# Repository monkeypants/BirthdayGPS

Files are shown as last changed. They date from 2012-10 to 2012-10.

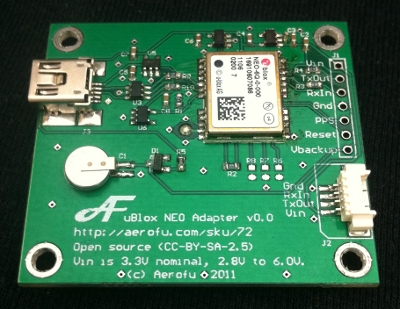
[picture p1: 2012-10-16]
images/bottom_cropped_400.jpg

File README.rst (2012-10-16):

BirthdayGPS v0.1
================

These files are hardware designs for the BirthdayGPS, more information is available here:

http://aerofu.com/index.php?products_id=72

or here:

http://aerofu.com/sku/72

The designs are free open source, released under the CC-BY-SA licence, available here:

http://creativecommons.org/licenses/by-sa/2.5/

Copyright is held by Chris Gough (a.k.a. aerofu.com).

Attribution
-----------

Attribution in derived works must includes both a link to the aerofu.com web site and an appropriate reference the BirthdayGPS brand name.

Share Alike
-----------

Derived works must be made available under CC-BY-SA licence version 2.5 or later. It is not permitted to distribute a derived work a more restrictive licence, such as with a "non-commercial" clause for example.

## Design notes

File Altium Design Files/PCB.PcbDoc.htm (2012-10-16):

Altium Reporting Options

# File in Previous Format

Date | : | 7/31/2012
Time | : | 1:21:46 PM
Filename | : | D:\from_old_workstation\personal\BirthdayGPS\Birthday GPS v0.1\Altium Design Files\PCB.PcbDoc

Version | Warning
Summer 09 | CAUTION - File contains old violation objects. These violations are no longer supported & will not be loaded.Please run DRC after opening this file in order to refresh the violations.
Summer 09 | CAUTION - Existing testpoint rules and settings are used as fabrication testpoint information.

This file was generated by an earlier version of the software

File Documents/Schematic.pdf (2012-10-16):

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
D | D
C | C
B | B
A | A

1

AeroFu
PO Box 5166
Kingston
NSW
1 | Australia 2606

## uBlox NEO Adapter

0.1
03/02/2012
Andrew Gough, copyright Aerofu 2011, Open source (CC-BY-SA-2.5). See http://aerofu.com/sku/72 for details.

Title

Size: | Number:
Date:
Author:

Revision:
Sheet of

A4

NC 1
SS_N 2
PPS 3
ExtInt 4
USB_DM 5
USB_DP 6
VddUSB 7

ResetN 8
VccRF 9
Gnd 10
RF_In 11
Gnd 12 | Gnd | 13 MOSI-CFG0 | 14 MISO-CFGCom1 | 15 SCK-CFGGPS0 | 16 NC | 17
SDA2 | 18 SCL2 | 19 TxD | 20 RxD | 21 V_Bckp | 22 Vcc | 23 Gnd | 24

U1

uBlox-Neo

V3.0

1Ant1

Patch Antenna

Pins for hand soldering

V | | | 1
ID | 4 DP | 3 DM | 2
Gnd | | | 5

J3

Molex picoblade

3.0V LDO Regulator | 3.3 LDO Regulator

Vin 1

Vss

2

CE 3 | (NC) | 4
| Vout | 5

U2 LT1761ES5-3

Vin 1

Vss

2

CE 3 | (NC) | 4
| Vout | 5

U5 LT1761ES5-3
Vin 1

Vss

2

CE 3 | (NC) | 4
| Vout | 5

U6 TC1015-3.3VCT713

47K

R1

V3.0

1uF

C5
1uF

C7
1uF

C8

R10 22R

R9 22R

V5-USB

3.0V LDO Regulator

V5-USB | V5-USB

V3.0

1uF

C4

### USB Components - Optional

1
2
3
4

J2

TxOut
RxIn
Gnd

220mF

C1

D1

100R

R5

V3.0

1uF

C2

Vbackup | SCL 1

Vss

2

SDA 3

Vcc | 4
WP | 5

U4

32k EEPROM

V3.0

SCL
SDA

100nF

C6

### Non-Volatile feature components - Optional

Vbackup

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
TxOut
RxIn
Gnd
PPS
Reset
Vbackup

or header

### Interconnect

RxIn
TxOut

Vin
<
<

Reset

PPS

Vin

IO1 1

IO2 3 | GND 2 | IO2 | 4 Vbus | 5 IO1 | 6

U3

ESD Protection | 1uF C3

Vin

### Main Power supply

V5-USB

(Optional)

ESD Protection

3.3K

R2

DNF

R7
DNF

R6
DNF

R8

CFG-GPS

CFG-C0

CFG-C1

R5 Allows the use of external reset.

DM
DP
M1 | M2 | M3 | M4

R3 1K
R4 1K

R3 and R4 protect IO from different logic levels.

R6, R7, R8 can be used

Mount holes

For normal use, Only Vin, Rx, Tx and Gnd need be connected.

V3.3-USB

for configuration.

# Notes:

Vin should be between 2.8V and 6V. Lower voltages mean that the uBlox Neo might not receive it's required minimum voltage of 2.7V. Higher voltages will generate more heat in the regulator U2, and may reduce operating temperature range.

IO voltages are nominally 3.0V. If connected to 3.3V or 5V logic, R3 will prevent the Rx line from taking too much current through it's rail clamp diode. If connected to 1.8Vlogic, R4 should protect
that devices Rx line likewise. No such protection has been provided for PPS.

The Reset line should only be controlled by an open drain device to avoid contention. A reset generator is provided on board the NEO series, so use of external Reset is optional.

The USB circuit is optional, and allows connection to the NEO through it's USB interface. If USB is not required, then all components in the above box can be removed. R1 is still required.

The power from USB and Vin are both regulated to 3.0V. If both sources are present, there should be no contention as long as regulators with reverse voltage protection are used. The LT1761 regulators have this protection. If only USB operation is required, the main power supply components can be removed.

Micochip 24AA32A

Two forms of non-volatile storage are supported. The Super-cap C1 allows the NEO module to shutdown and preserve it's configuration settings, assistance information and time. It should provide the back-up supply voltage for several hours. Beyond this time, assistance and time data become less usefull for receiver start-up. If the EEPROM is not used, then it is essential to provide the receiver configuration commands on boot every time.

Too preserve the configuration settings, the EEPROM U4 may be used. This is not large enough to allow the receiver to store assistance data. This I2C EEPROM can be removed if not required.

The settings can also be configured by using R6, R7 and R8. These allow CFG-GPS, CFG-Com1 and CFG-Com0 bits to be set on start-up. These can be used to set some of the operating configuration of the NEO unit.

Vbackup can be used to provide an external backup battery. It's voltage must not exceed 3.3V if Super-cap C1 is fitted, or 3.6 V if it is not. If a lower than 3.0V supply is used, either R5 or D1 must be removed.

### LED Indicators - Optional

D2
Green

D3
Red

V3.0 PPS

Two LED's can be used. These are not required. If fitted, D2 will show the presence of power from either Vin or USB. D3 is connected to PPS, and will show the unit is tracking, as long as the PPS is configured for a fairly long pulse, say 100ms. If the PPS is configured for a pulse of several us, then this will not be visible on the LED.

220R

R11
220R

R12

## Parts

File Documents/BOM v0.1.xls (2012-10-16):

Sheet: BOM Report
Bill of Materials
Project: |  | Birthday GPS
Design Version: |  | 0.1
BOM Version: |  | 0.1
Creation Date: | 2012-02-02
Designator | Part | Description | Comment | Source | Alternate Source | Quantity
Ant1 | Taoglas GP.1575.25.4.A.02 | 25 mm Patch antenna | Through Hole, Bottom side | Digikey: 931-1015-ND |  | 1
C1 | Elna DCK-3R3E224U-E | SuperCap, 6.8 mm, 220 mF, 3.3V | SMD, Top side | Digikey: 604-1007-ND |  | 1
C2, C3, C4, C5, C7, C8 | Murata GRM188R61E105KA12D | Capacitor 0603, 1uF, 25V | SMD, Top side | Digikey: 490-3897-1-ND |  | 6
C6 | Murata GRM188R71C104KA01D | Capacitor 0603, 100nF, 16V | SMD, Top side | Digikey: 490-1532-1-ND |  | 1
D1 | Generic Diode BAS116 | Silicon Low Leakage Diode, sot23-3 | SMD, Top side | Digikey: BAS116-FDICT-ND |  | 1
D2 | Osram LG Q971-KN-1 | Green LED, 0603. | SMD, Top side | Digikey: 475-1409-1-ND |  | 1
D3 | Osram LS Q976-NR-1 | Red LED, 0603 | SMD, Top side | Digikey: 475-2512-1-ND |  | 1
J1 | DNF | Graphic only for header | DNF |  |  | 0
J2 | Molex 53261-0471 | 4 pin Molex Picoblade Socket | SMD, Top side | Digikey: WM7622CT-ND |  | 1
J3 | TE 1734035-2 | USB Connector – Mini USB B | SMD, Top side | Digikey: A31727CT-ND |  | 1
M1, M2, M3, M4 | DNF | Graphic only - Mount Holes | DNF |  |  | 0
R1 | Yaego RC0603JR-0747KL | 47k Ohm 0603 Resistor | SMD, Top side | Digikey: 311-47KGRCT-ND |  | 1
R2 | Yaego RC0402JR-073K3L | 3.3k Ohm 0603 Resistor | SMD, Top side | Digikey: 311-3.3KJRCT-ND |  | 1
R3, R4 | Yaego RC0603FR-071KL | 1k Ohm 0603 Resistor | SMD, Top side | Digikey: 311-1.00KHRCT-ND |  | 2
R5 | Yaego RC0402JR-07100RL | 100 Ohm 0603 Resistor | SMD, Top side | Digikey: 311-100JRCT-ND |  | 1
R6, R7, R8 | DNF | DNF Resistors | DNF |  |  | 0
R9, R10 | Yaego RC0603JR-0722RL | 22 Ohm 0603 Resistor | SMD, Top side | Digikey: 311-22GRCT-ND |  | 2
R11, R12 | Yaego RC0603JR-07220RL | 220 Ohm 0603 Resistor | SMD, Top side | Digikey: 311-220GRCT-ND |  | 2
U1 | u-blox Neo 6Q | GPS Module | SMD, Top side | Braemac: uBlox NEO-6Q |  | 1
U2, U5 | Linear Tech LT1761ES5-3 | LDO Regulator, Sot-23-5, 3.0V | SMD, Top side | Digikey: LT1761ES5-3#TRMPBFCT-ND | From Stock | 2
U3 | ST USBLC6-2 | ESD Protection, Sot23-6 | SMD, Top side | Digikey: 497-5235-1-ND |  | 1
U4 | Microchip 24AA32A | EEPROM, 32k, Sot23-5 | SMD, Top side | Digikey: 24AA32AT-I/OTCT-ND |  | 1
U6 | TC1015-3.3VCT713 | LDO Regulator, Sot-23-5, 3.3V | SMD, Top side | Digikey: TC1015-3.3VCT713CT-ND |  | 1
 |  |  |  |  |  | 29
Approved |  | Notes

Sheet: Project Information
Project Full Path | C:\Work\NEO GPS Board\PCB_Project.PrjPCB
Project Filename | PCB_Project.PrjPCB
Variant Name | None
Data-Source Filename | PCB_Project.PrjPCB
Data-Source Full Path | C:\Work\NEO GPS Board\PCB_Project.PrjPCB
Title | Bill of Materials For Project [PCB_Project.PrjPCB] (No PCB Document Selected)
Total Quantity | 37
Report Time | 19:00:43
Report Date | 2012-02-04
Report Date & Tine | 2012-02-04 19:00
Output Name | Bill of Materials
Output Type | BOM_PartType
Output Generator Name | ReportComponents
Output Generator Description | Component Reports

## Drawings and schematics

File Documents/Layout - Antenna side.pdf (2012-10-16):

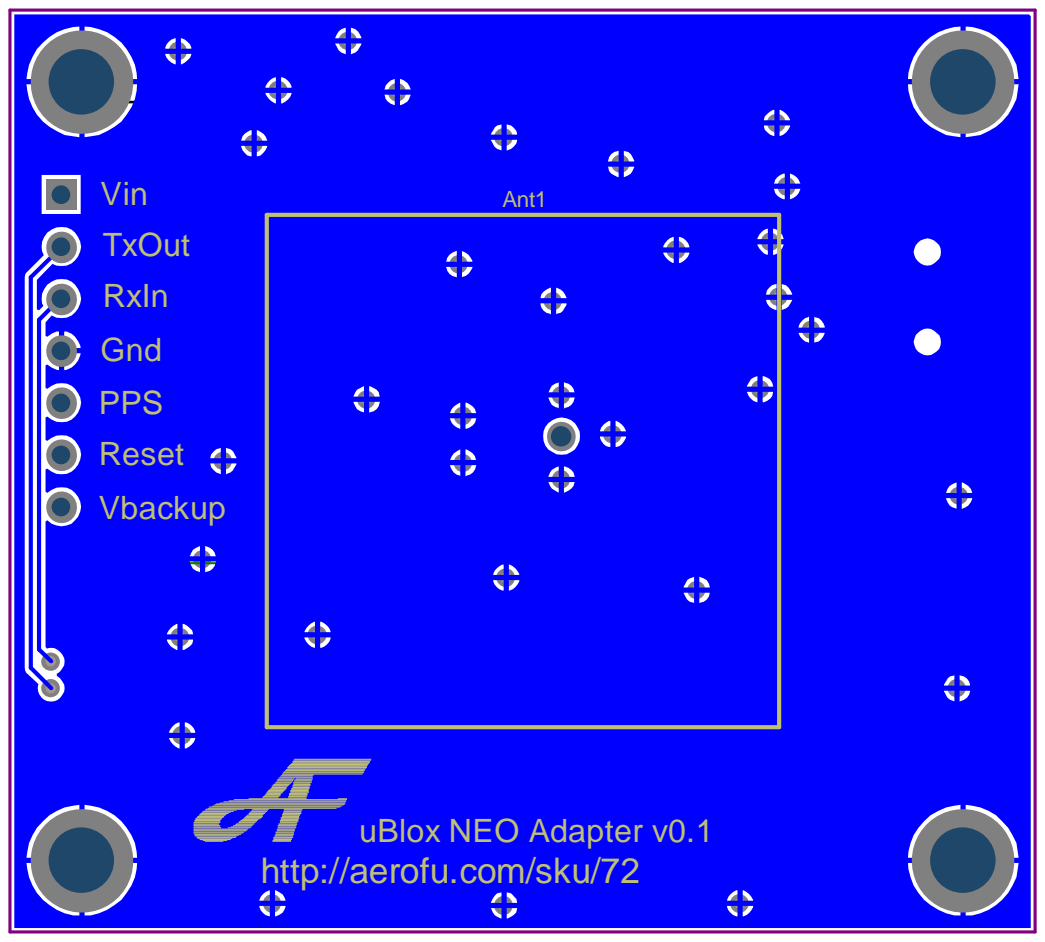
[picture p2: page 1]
Reset Vbackup; RxIn; Ant1; TxOut; PPS; Vin; Gnd

uBlox NEO Adapter v0.1
http://aerofu.com/sku/72

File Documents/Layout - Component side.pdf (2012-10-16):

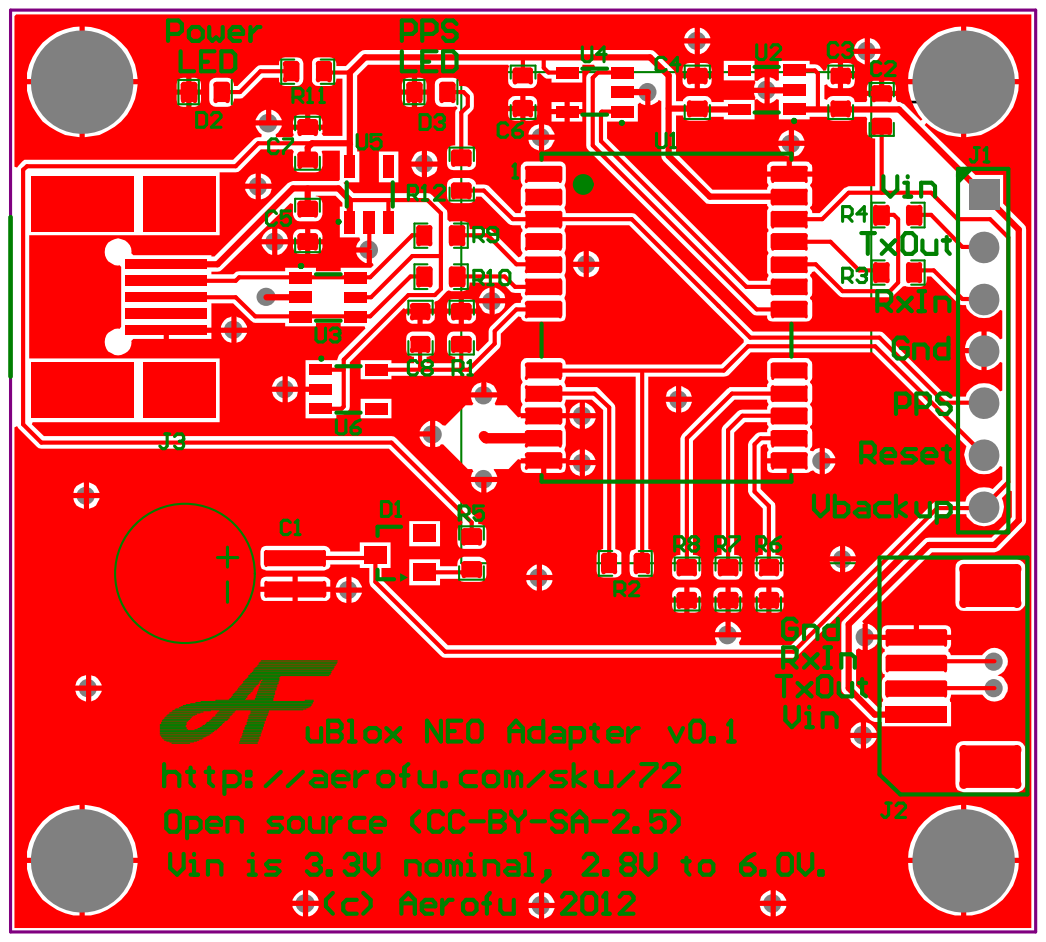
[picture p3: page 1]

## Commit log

2012-10-16 Added the missing files (from aerofu.com).
    OK, now this is a non-empty repository :)
    [BOM v0.1.xls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]
2012-10-16 switching to ReStructured Text,
    I hope GitHub is cool with that, I'd rather use it than markdown.
